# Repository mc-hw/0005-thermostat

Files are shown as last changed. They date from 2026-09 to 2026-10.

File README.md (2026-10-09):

# Thermostat (0005)

A thermostat indicating _too low/OK/too high_ temperature with LEDS.

## Description

This circuit is a copy of [AVT-1742](./AVT1742.pdf) converted to Surface Mounted Technology.

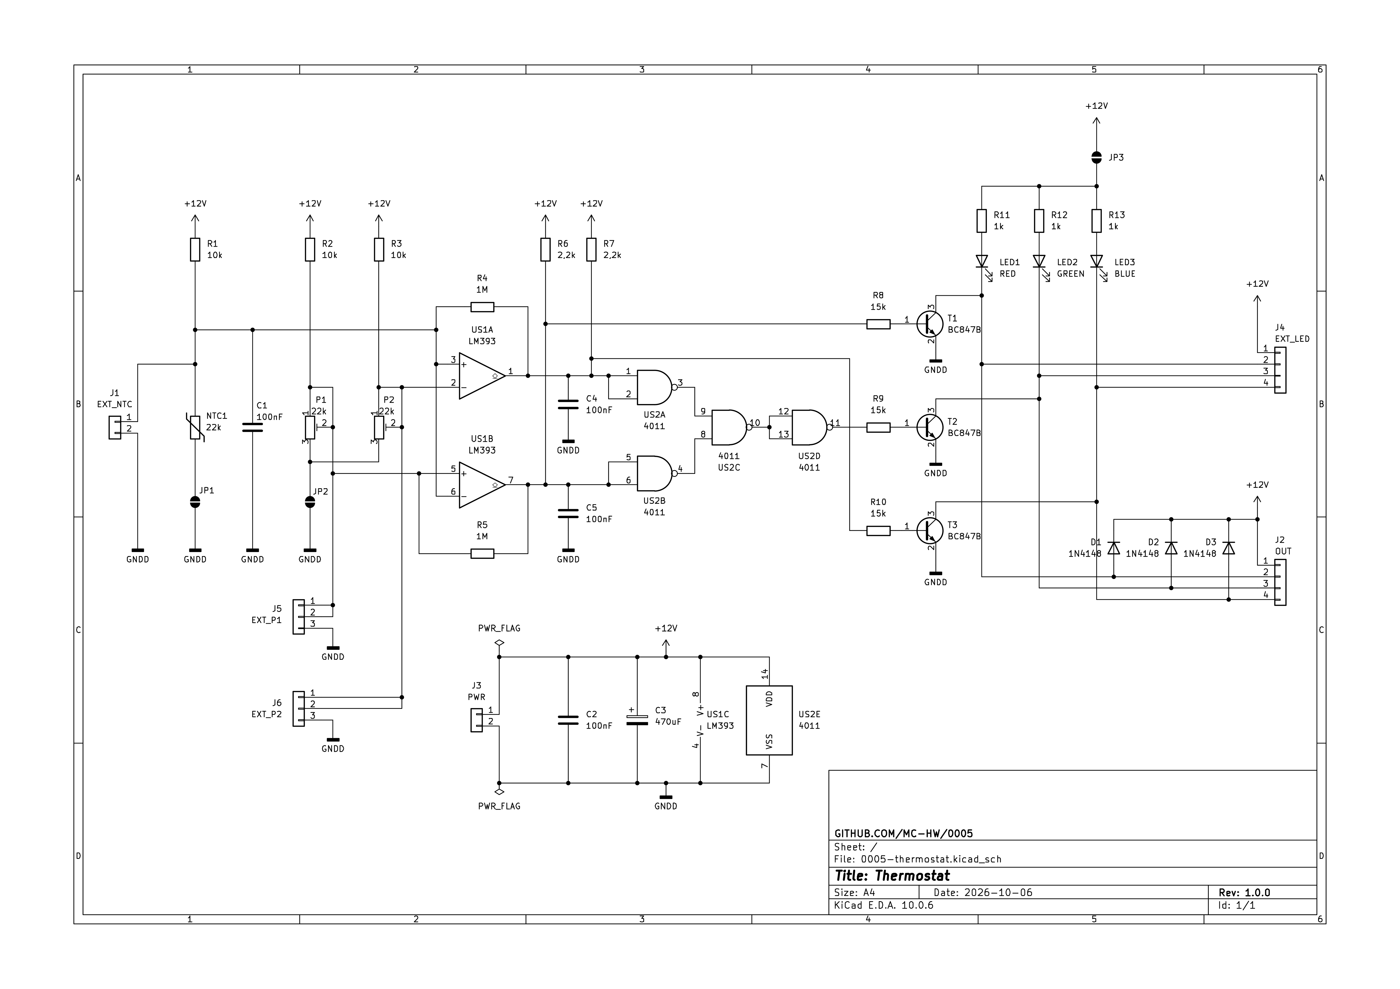
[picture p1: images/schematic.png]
Schematic


## Assembly

This circuit should be assembled on a double-sided, SMT printed circuit board.

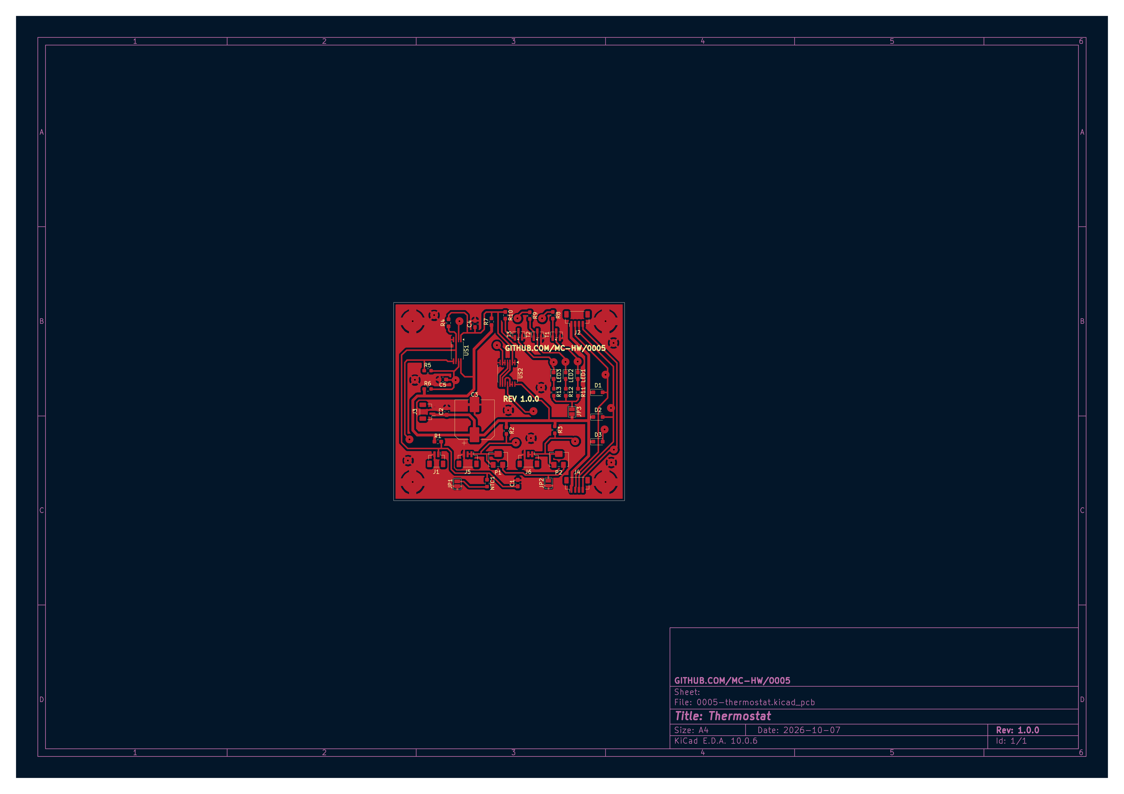
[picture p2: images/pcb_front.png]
PCB front layout


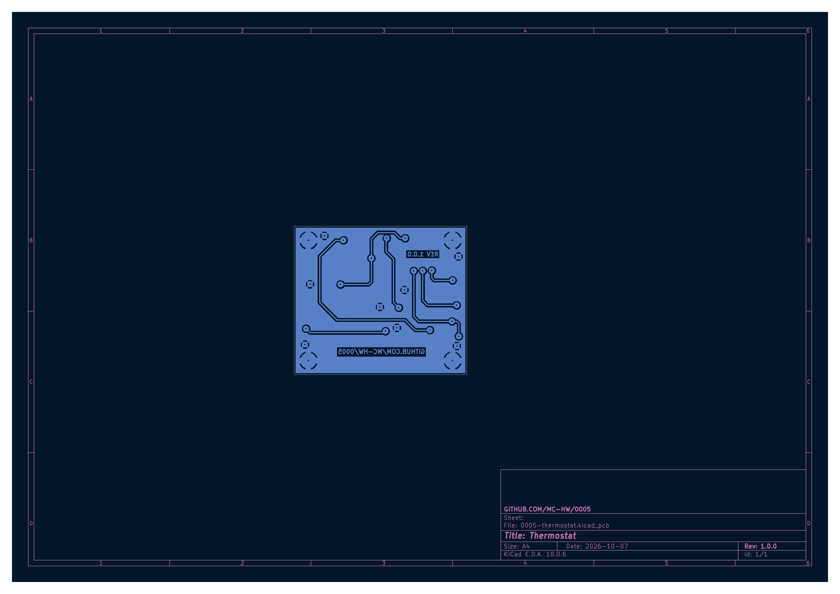
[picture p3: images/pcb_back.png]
PCB back layout


## Running

The device should be powered with 12VDC connected to J3 junction (mind the polarization).

Comparing to the original solution, either a thermistor embedded into the PCB or the external thermistor connected to
junction J1 can be used. Jumper JP1 should be soldered when the embedded thermistor is used, or de-soldered when the
external thermistor is used.

The high/lowh temperature thresholds should be calibrated using potentiometers P1 and P2, or external potentiometers
connected to J5 and J6. Jumper JP2 should be soldered when the embedded potentiometers are used, or de-soldered when the
external potentiometers are used.

The thresholds (low/ok/high) are presented with LED1 (high), LED2 (OK) and LED3 (low), or external LEDs connected to
junction J4 (LED current limiting resistors are required, open-collector outputs). Jumper JP3 should be soldered when
the embedded LEDs are used, or de-soldered when the embedded LEDs are not used.

The thresholds can be used to trigger external devices (e.g. using relays). External devices should be connected to
junction J2 (coil current limiting resistors are required, open-collector outputs; the current should be <80mA -
limitation of BC847B transistor; recommended current <40mA, as it's possible that two signals are enabled due to
incorrect calibration).

## Bill of materials

| Reference | Qty | Value | Footprint |
|:---|:----|:---|:---|
| C1,C2,C4,C5 | 4 | 100nF | 0603 |
| C3 | 1 | 470uF | Electrolytic D=10mm |
| D1,D2,D3 | 3 | 1N4148 | SOD-323 |
| J1 | 1 | EXT\_NTC | JST-SH 1x2 Vertical |
| J2 | 1 | OUT | JST-SH 1x4 Vertical |
| J3 | 1 | PWR | JST-SH 1x2 Vertical |
| J4 | 1 | EXT\_LED | JST-SH 1x4 Vertical |
| J5 | 1 | EXT\_P1  | JST-SH 1x3 Vertical |
| J6 | 1 | EXT\_P2  | JST-SH 1x3 Vertical |
| LED1 | 1 | RED | 0603 |
| LED2 | 1 | GREEN | 0603 |
| LED3 | 1 | BLUE | 0603 |
| NTC1 | 1 | 22k | 0603 |
| P1,P2 | 2 | 22k | Bourns_3224W_Vertical |
| R1,R2,R3 | 3 | 10k | 0603 |
| R4,R5 | 2 | 1M | 0603 |
| R6,R7 | 2 | 2,2k | 0603 |
| R8,R9,R10 | 3 | 15k | 0603 |
| R11,R12,R13 | 3 | 1k | 0603 |
| T1,T2,T3 | 3 | BC847B | SOT-23 |
| US1 | 1 | LM393 | TSSOP-8 4.4mm x 3mm |
| US2 | 1 | 4011 | TSSOP-14 4.4mm x 5mm  |

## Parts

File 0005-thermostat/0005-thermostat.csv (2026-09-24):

Reference | Qty | Value | Footprint
C1,C2,C4,C5 | 4 | 100nF | Capacitor_SMD:C_0603_1608Metric_Pad1.08x0.95mm_HandSolder
C3 | 1 | 470uF | Capacitor_SMD:CP_Elec_10x10
D1,D2,D3 | 3 | 1N4148 | Diode_SMD:D_SOD-323_HandSoldering
J1 | 1 | EXT_NTC | Connector_JST:JST_SH_BM02B-SRSS-TB_1x02-1MP_P1.00mm_Vertical
J2 | 1 | OUT | Connector_JST:JST_SH_BM04B-SRSS-TB_1x04-1MP_P1.00mm_Vertical
J3 | 1 | PWR | Connector_JST:JST_SH_BM02B-SRSS-TB_1x02-1MP_P1.00mm_Vertical
J4 | 1 | EXT_LED | Connector_JST:JST_SH_BM04B-SRSS-TB_1x04-1MP_P1.00mm_Vertical
J5 | 1 | EXT_P1 | Connector_JST:JST_SH_BM03B-SRSS-TB_1x03-1MP_P1.00mm_Vertical
J6 | 1 | EXT_P2 | Connector_JST:JST_SH_BM03B-SRSS-TB_1x03-1MP_P1.00mm_Vertical
LED1 | 1 | RED | LED_SMD:LED_0603_1608Metric_Pad1.05x0.95mm_HandSolder
LED2 | 1 | GREEN | LED_SMD:LED_0603_1608Metric_Pad1.05x0.95mm_HandSolder
LED3 | 1 | BLUE | LED_SMD:LED_0603_1608Metric_Pad1.05x0.95mm_HandSolder
NTC1 | 1 | 22k | Resistor_SMD:R_0603_1608Metric_Pad0.98x0.95mm_HandSolder
P1,P2 | 2 | 22k | Potentiometer_SMD:Potentiometer_Bourns_3224W_Vertical
R1,R2,R3 | 3 | 10k | Resistor_SMD:R_0603_1608Metric_Pad0.98x0.95mm_HandSolder
R4,R5 | 2 | 1M | Resistor_SMD:R_0603_1608Metric_Pad0.98x0.95mm_HandSolder
R6,R7 | 2 | 2,2k | Resistor_SMD:R_0603_1608Metric_Pad0.98x0.95mm_HandSolder
R8,R9,R10 | 3 | 15k | Resistor_SMD:R_0603_1608Metric_Pad0.98x0.95mm_HandSolder
R11,R12,R13 | 3 | 1k | Resistor_SMD:R_0603_1608Metric_Pad0.98x0.95mm_HandSolder
T1,T2,T3 | 3 | BC847B | Package_TO_SOT_SMD:SOT-23
US1 | 1 | LM393 | Package_DFN_QFN:DFN-8-1EP_2x2mm_P0.5mm_EP0.8x1.6mm
US2 | 1 | 4011 | Package_SO:TSSOP-14_4.4x5mm_P0.65mm

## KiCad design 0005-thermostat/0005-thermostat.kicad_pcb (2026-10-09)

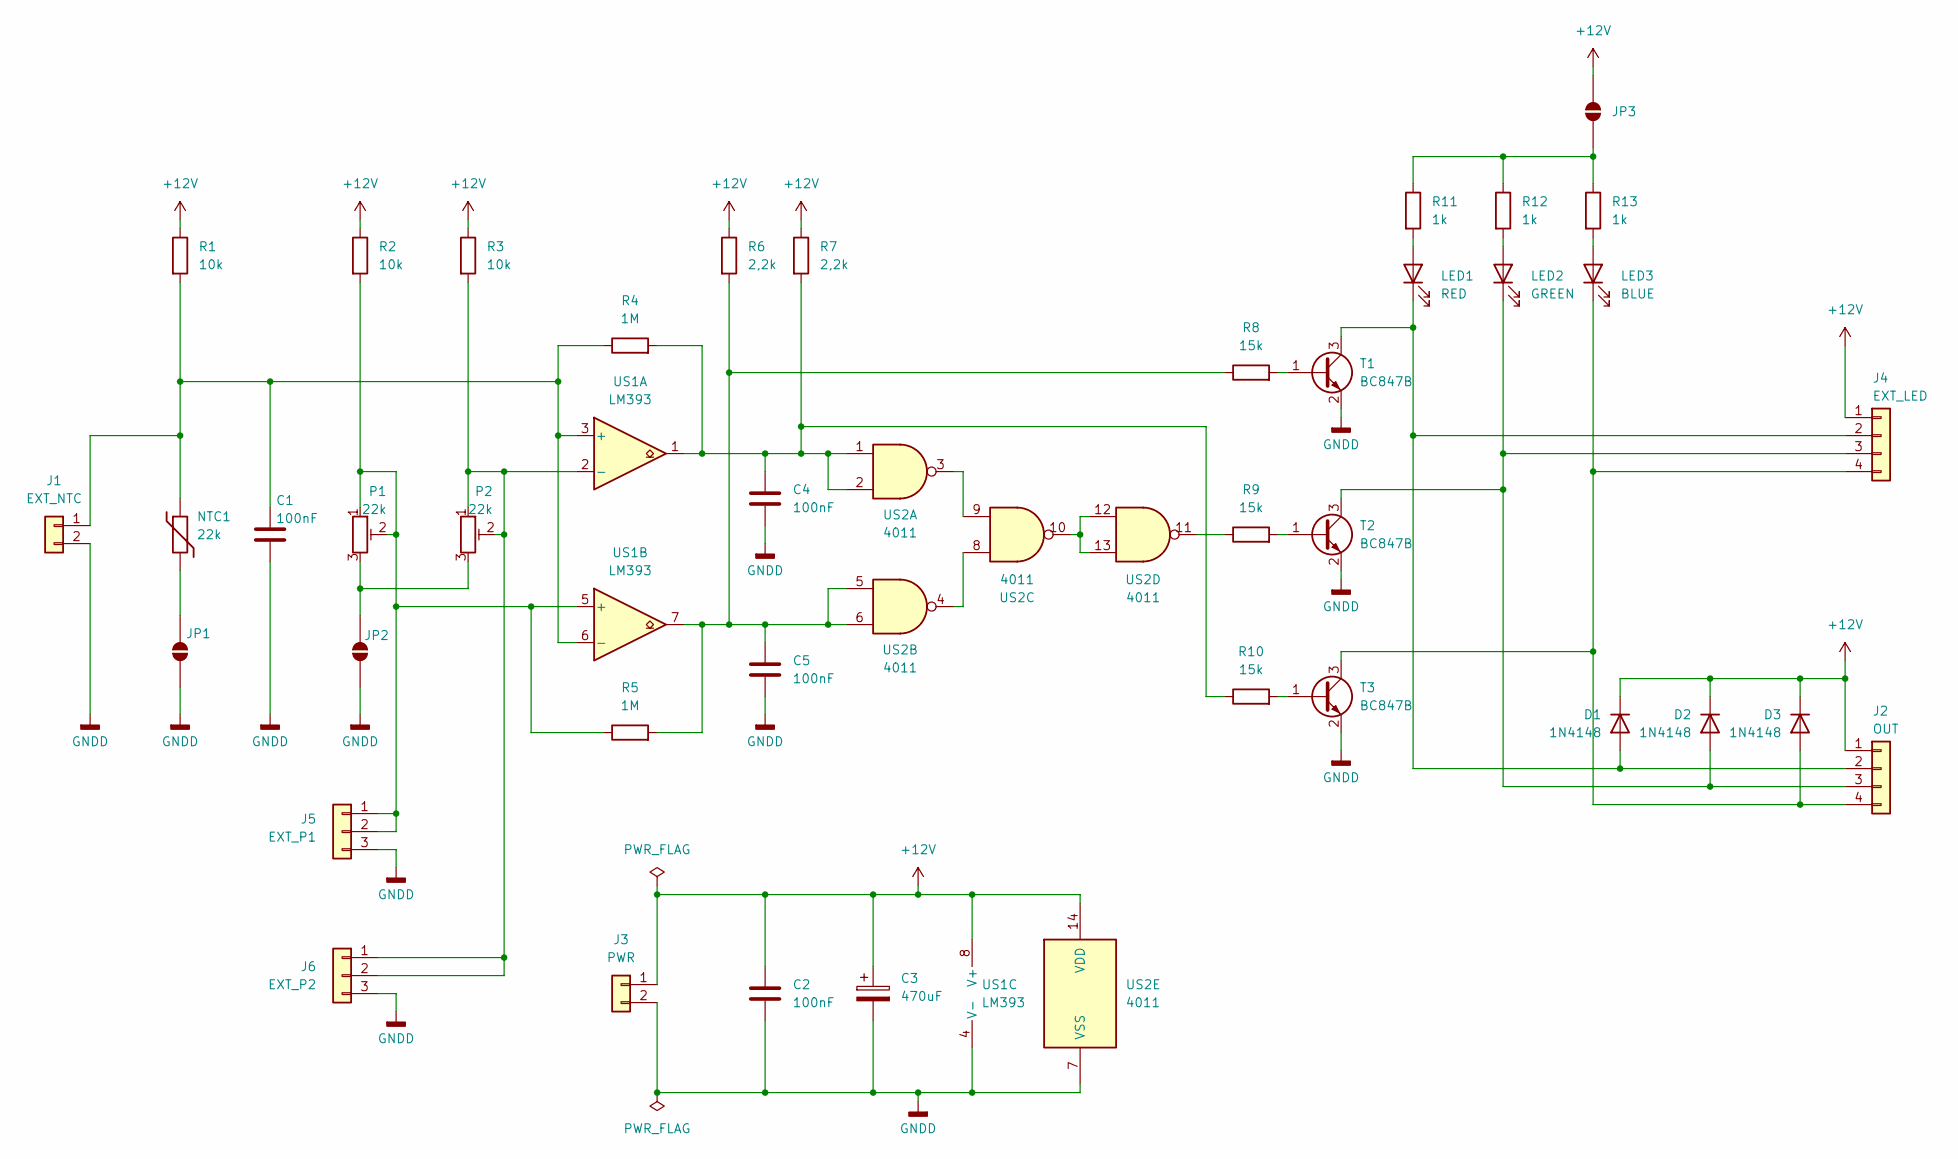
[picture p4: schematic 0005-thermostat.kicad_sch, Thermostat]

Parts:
C1, C2, C4, C5: 100nF; C_0603_1608Metric_Pad1.08x0.95mm_HandSolder
C3: 470uF; CP_Elec_10x10
D1, D2, D3: 1N4148; D_SOD-323_HandSoldering
J1: EXT_NTC; JST_SH_BM02B-SRSS-TB_1x02-1MP_P1.00mm_Vertical
J2: OUT; JST_SH_BM04B-SRSS-TB_1x04-1MP_P1.00mm_Vertical
J3: PWR; JST_SH_BM02B-SRSS-TB_1x02-1MP_P1.00mm_Vertical
J4: EXT_LED; JST_SH_BM04B-SRSS-TB_1x04-1MP_P1.00mm_Vertical
J5: EXT_P1; JST_SH_BM03B-SRSS-TB_1x03-1MP_P1.00mm_Vertical
J6: EXT_P2; JST_SH_BM03B-SRSS-TB_1x03-1MP_P1.00mm_Vertical
JP1, JP2, JP3: SolderJumper_2_Open; SolderJumper-2_P1.3mm_Open_Pad1.0x1.5mm
LED1: RED; LED_0603_1608Metric_Pad1.05x0.95mm_HandSolder
LED2: GREEN; LED_0603_1608Metric_Pad1.05x0.95mm_HandSolder
LED3: BLUE; LED_0603_1608Metric_Pad1.05x0.95mm_HandSolder
NTC1: 22k; R_0603_1608Metric_Pad0.98x0.95mm_HandSolder
P1, P2: 22k; Potentiometer_Bourns_3224W_Vertical
R1, R2, R3: 10k; R_0603_1608Metric_Pad0.98x0.95mm_HandSolder
R4, R5: 1M; R_0603_1608Metric_Pad0.98x0.95mm_HandSolder
R6, R7: 2,2k; R_0603_1608Metric_Pad0.98x0.95mm_HandSolder
R8, R9, R10: 15k; R_0603_1608Metric_Pad0.98x0.95mm_HandSolder
R11, R12, R13: 1k; R_0603_1608Metric_Pad0.98x0.95mm_HandSolder
T1, T2, T3: BC847B; SOT-23
US1: LM393; TSSOP-8_4.4x3mm_P0.65mm
US2: 4011; TSSOP-14_4.4x5mm_P0.65mm

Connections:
+12V: C2.1, C3.1, D1.1 (K), D2.1 (K), D3.1 (K), J2.1, J3.1, J4.1, JP3.1 (A), R1.1, R2.1, R3.1, R6.1, R7.1, US1.8 (V+), US2.14 (VDD)
GNDD: C1.2, C2.2, C3.2, C4.2, C5.2, J1.2, J1.MP, J2.MP, J3.2, J3.MP, J4.MP, J5.3, J5.MP, J6.3, J6.MP, JP1.1 (A), JP2.1 (A), T1.2 (E), T2.2 (E), T3.2 (E), US1.4 (V-), US2.7 (VSS)
unnamed: C4.1, R4.2, R7.2, R10.1, US1.1, US2.1, US2.2
unnamed: C5.1, R5.2, R6.2, R8.1, US1.7, US2.5, US2.6
unnamed: D1.2 (A), J2.2, J4.2, LED1.1 (K), T1.3 (C)
unnamed: D2.2 (A), J2.3, J4.3, LED2.1 (K), T2.3 (C)
unnamed: D3.2 (A), J2.4, J4.4, LED3.1 (K), T3.3 (C)
unnamed: C1.1, J1.1, NTC1.1, R1.2, R4.1, US1.3 (+), US1.6 (-)
unnamed: J5.1, J5.2, P1.1, P1.2, R2.2, R5.1, US1.5 (+)
unnamed: J6.1, J6.2, P2.1, P2.2, R3.2, US1.2 (-)
unnamed: JP1.2 (B), NTC1.2
unnamed: JP2.2 (B), P1.3, P2.3
unnamed: JP3.2 (B), R11.1, R12.1, R13.1
unnamed: LED1.2 (A), R11.2
unnamed: LED2.2 (A), R12.2
unnamed: LED3.2 (A), R13.2
unnamed: R9.1, US2.11
unnamed: R8.2, T1.1 (B)
unnamed: R9.2, T2.1 (B)
unnamed: R10.2, T3.1 (B)
unnamed: US2.3, US2.9
unnamed: US2.4, US2.8
unnamed: US2.10, US2.12, US2.13

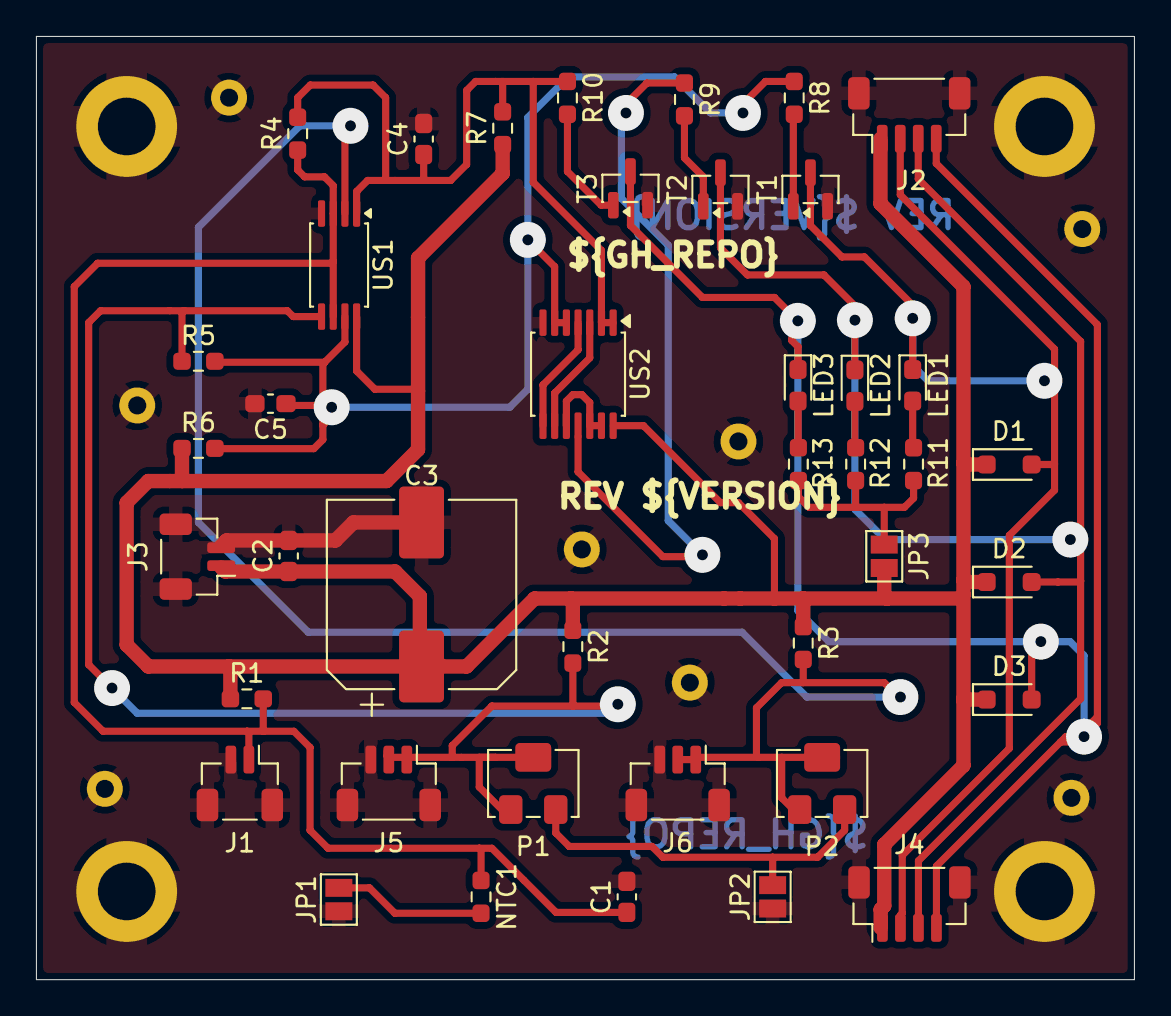
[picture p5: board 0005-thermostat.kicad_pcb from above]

Board: 2 copper layers, 61.0 x 52.4 mm, 41 parts (0 on the bottom side), 23 nets.

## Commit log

2026-09-18 Initial schematic (#1)
    * Initial schematic: power, comparator, nand gates
    * Add jumber for thermistor
    * Schematic complete
    * Schematic enhancement
    * Update footprints
    * Enhance schematic and fix validation errors
    * Export schematic and place in README
    * Improve schematic image in README
    [0005-thermostat.kicad_pcb, 0005-thermostat.kicad_sch]
2026-09-21 Initial documentation (#2)
    * Initial documentation
    [0005-thermostat.kicad_sch]
2026-09-24 Assign footprints, generate BOMs (#3)
    [0005-thermostat.csv, 0005-thermostat.kicad_sch]
2026-09-27 Start PCB design (#4)
    * Start PCB design
    * PCB - new sections designed
    * PCB design - connecting modules
    * PCB finished
    * Update images
    [0005-thermostat.kicad_pcb]
2026-09-29 PCB update (#5)
    * PCB update
    * Update PCB printouts
    * Update PCB
    * Replace 12DCV with 12VDC
    * Update PCB
    * fix pcb design
    * Slight PCB updates
    * Update PCB images
    * Update PCB back image
    [0005-thermostat.kicad_pcb]
2026-10-09 PCB enhancement (#6)
    * PCB enhancement
    * Redesign power plug
    * Small PCB changes
    * Redesign another sections
    * Re-design comparator section, shrink the board
    * Redesigned PCB shape
    * Replace SOIC to TSSOP ICs footprints
    [0005-thermostat.kicad_pcb, 0005-thermostat.kicad_sch]
2026-10-12 Plotted gerbers (#7)
2026-10-22 Add solder mask to vias (#8)
